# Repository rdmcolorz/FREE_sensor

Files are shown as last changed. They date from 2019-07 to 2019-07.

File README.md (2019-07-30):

# FREE Sensor
_"Wildfires have changed, It's time the technology to fight them does too."_

FREE Sensor is a device firefighters use to detect harmful gasses and to track status of individual firefighters. 

title (https://www.youtube.com/watch?v=2XaswEznusA&feature=youtu.be)
_click for video_

## IBM Cloud services

`IBM Watson IoT Platform` for streaming IoT data and managing IoT devices  
`Cloudant` database for storing history IoT data  
`IBM Watson Studio / Data refinery` for data transformation and parsing  
`IBM Watson Studio / Cognos Dashboard` for data visualization and analytics  

## Getting Started

Follow this [tutorial](https://developer.ibm.com/recipes/tutorials/run-an-esp8266arduino-as-a-iot-foundation-managed-device/) to connect ESP8266 with the IoT platform. For current setup, on the IBM Watson IoT Platform, change `Default Rule` in `Security` to `TLS Optional` to connect with ESP.

To setup history database for IoT data, go to `Extensions` > `Histroical Data Storage` and choose the `Cloudant` service you have created.

Open `IBM Watson Studio` to get access to the database and add connection.

Please message [Taylor](rainbowwww5@gmail.com) to be added to the Watson Studio project.

### Prerequisites

For Taylor's setup you will be using these hardware products:

* [NodeMCU Esp8266](https://www.handsontec.com/pdf_learn/esp8266-V10.pdf) - Main microprocessor
* [Beginner's Guide to ESP8266](https://tttapa.github.io/ESP8266/Chap01%20-%20ESP8266.html)
* [Adafruit SHT31-D Temperature & Humidity Sensor Breakout](https://learn.adafruit.com/adafruit-sht31-d-temperature-and-humidity-sensor-breakout/assembly) - Temperature / Humidity Sensor breakout board
* [MicroSD Shield Adapter](https://www.ebay.com/i/173320605763?itemid=173320605763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) - MicroSD card reader
* [Powered Carbon Monoxide Sensor](https://cdn.sparkfun.com/datasheets/Sensors/Biometric/MQ-7%20Ver1.3%20-%20Manual.pdf) - First prototype sensor
* [Low Power Carbon Monoxide Sensor](https://www.spec-sensors.com/wp-content/uploads/2016/04/3SP_CO_1000-C-Package-110-109.pdf) - Second prototype sensor
* [Adafruit GPS breakout board](https://cdn-learn.adafruit.com/downloads/pdf/adafruit-ultimate-gps.pdf) - GPS module

## Prototyping

Our early prototyping consisted of taking individual sensor components and producing a serial communication readout of the live data. We used the NodeMCU controller to drive the other sensors. 

foo Prototype 1
bar Prototype 2

One major setback we faced was the original CO sensor we used. The sensor die had an operating temperature of over 100°C. This was a massive drain on our battery, and ultimately the bottleneck in miniturizing our device. Thankfully, we found an alternative sensor that has an extremely low-power profile and rated to remain opperational for nearly ten years. This significantly freed up constraints on how small and light our device could become.
There is a limitation using the original MQ-7 sensor as it requires a 90 second warm-up phase and can then collect data and average over one minute for accurate results. This limits data gathering to once every 5 or 10 minutes depending on the final battery used and needed battery life in the field. 
The roadmap for the hardware will include evaluating the 3SP_CO_1000 Spec Sensor, which requires no warmup, but is more expensive. We will also add GPS and humidity sensors. 

Once we tested all the sensors and had their output saving accurately, we combined their output into a test .csv to feed into the IBM cloud. Once on the cloud, we could start analyzing and visualizing the data using IBM computing services. This allowed us to produce remarkable information from our sensor data.

When we started working on IBM Cloud, it was simple to set up an IoT platform and start using simulated devices to get a sense of what data is collected. There was also documentation on setting up an esp8266 device to connect to the platform which was exactly what we needed. Collecting the historic data by setting up a Cloudant for IoT data storage is also quick to implement. After the data is inside the database, we connected Watson studio to the data and used data refinery to parse and transform the data. After data refinery outputs the cleaned data, we can then push it to the Cognos Dashboard, where we can easily drag and drop data into graphs to visualize and analyze our data. We set up the whole pipeline without writing any code, which was a fast and easy experience!

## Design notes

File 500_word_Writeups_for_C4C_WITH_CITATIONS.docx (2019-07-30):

10 WORDS

Sensor data/analytics to reduce wildfire responder exposure to smoke.

499 WORDS

THE OPPORTUNITY

Wildfires have intensified in scale and impact in the last few decades¹. Yet there’s limited data available to understand the long-term effects of smoke exposure among first responders on the front lines². For instance, cardiovascular and neurological diseases are believed to be linked to high levels of carbon monoxide (CO) exposure²,³,⁴.

CO is one harmful component of smoke, is a toxic, odorless, colorless gas which can have immediate effects on physical and mental performance, often unnoticed by the person exposed⁵. Current methods of determining the prognosis and treatment can also be subjective and possibly dangerous⁴.

Our research indicated an opportunity to develop on-the-field technology to measure and record CO levels. The solution could also provide large-scale, quantitative data to study CO correlations with other harmful substances such as PM².⁵ and respirable crystalline silica found in smoke²,⁶,⁷,⁸. There’s no wearable, rugged, low-cost CO device available today.

Health professionals and other scientists can use this data to monitor and determine long-term effects of CO on first responders, and perhaps extrapolate the data to improve the clinical care of active and retired first responders.

OUR SOLUTION

The F.R.E.E. (First Responder Emission Evaluator) Sensor technology has two basic functions: 1) Data gathering and upload capabilities through a compact, rugged CO monitoring device worn by first responders in the field, and 2) Provision of a data dashboard, allowing support teams to make safer deployment decisions based on CO exposure of individual crew members.

The wearable CO sensor was designed with the following parameters: 1) Low cost, 2) IoT solution leveraging the IBM Cloud, 3) Built-in memory card, 4) Low power consumption for long battery life, and 5) Accuracy. IBM technologies employed are the DB2 database, Watson Studio for visualization, and IBM AI to analyze patterns that might help correlate CO levels to PM2.5 and other toxins exposure.

We constructed two prototypes. Both used the MQ-7 CO sensor, SD memory card, Arduino base board, and temperature sensor. Because the MQ-7 CO sensor consumes excessive power during warm-up, we are also evaluating the 3SP_CO_1000 Spec Sensor, a more expensive but low-power component.

The main prototype uploads data to the IBM Cloud via a micro USB cable, and the other uses a Bluno Arduino with built-in Bluetooth, allowing transfer via cellphone for upload to the Cloud when coverage is available.

We envision two uses for the data. The first would populate a data dashboard for support personnel charged with deploying fire crew resources. The data could be incorporated into existing resource management/scheduling software or we could provide a stand-alone dashboard app that fire captains can utilize on their cellphones. The second could be used by medical professionals and researchers to analyze impacts of cumulative exposure, help set occupational exposure limits, and improve the diagnosis and treatment of affected first responders.

F.R.E.E. Sensor is a groundbreaking opportunity to mine large-scale data from first responder CO exposure. Its data dashboard will be invaluable for rapid decision-making in managing fire crew exposure to smoke at the front lines.

REFERENCES

¹Kenward, A., Sanford, T., Bronzan, J. “Western Wildfires – A Fiery Future.” Climate Central. https://assets.climatecentral.org/pdfs/westernwildfires2016v2.pdf (accessed July 23, 2019).

²Domitrovich, J.W. et al. “Wildland Fire Smoke Health Effects on Wildland Firefighters and the Public” Joint Fire Science Program. https://wildfiretoday.com/documents/FirefighterSmokeHealthRisk.pdf (accessed July 23, 2019).

³ Beppu, T. “The Role of MR Imaging in Assessment of Brain Damage from Carbon Monoxide Poisoning: A Review of the Literature.” The American Journal of Neuroradiology, April 2014. http://www.ajnr.org/content/35/4/625 (accessed July 23, 2019).

⁴ Feng-You Lee, Wei-Kung Chen, Cheng-Li Lin, and Chia-Hung Kao. “Carbon Monoxide Poisoning and Subsequent Cardiovascular Disease Risk.” National Library of Medicine, National Institutes of Health. https://www.ncbi.nlm.nih.gov/pmc/articles/PMC4602477/ (accessed July 23, 2019).

⁵ CDC. “Clinical Guidance for Carbon Monoxide (CO) Poisoning After a Disaster.” Center for Disease Control and Prevention. https://www.cdc.gov/disasters/co_guidance.html (accessed July 23, 2019)

⁶ Urbanski, S.P. “Re[2]: Smoke composition ratios for CO and PM2.5 in Wildfires.” Message to Roy Stahl. 4 June 2019. Email.

⁷ Reinhardt, T.E. and Ottmar, R.D. “Baseline Measurements of Smoke Exposure Among Wildland Firefighters” Journal of Occupational and Environmental Hygiene. https://www.fs.fed.us/pnw/fera/publications/fulltext/reinhardtandottmar2004.pdf (accessed July 23, 2019).

⁸ Reinhardt, T.E., Ottmar, R.D and Hanneman, A.J.S. “Smoke Exposure

Among Firefighters at Prescribed Burns in the Pacific Northwest.” USDA Forest Service. https://www.fs.fed.us/pnw/pubs/pnw_rp526.pdf (accessed July 23, 2019).

OTHER interesting stuff:

How NASA measure CO from wildfires

https://climate.nasa.gov/news/2781/carbon-monoxide-from-california-wildfires-drifts-east/

High exposure increases risk of disease among firefighters

https://wildfiretoday.com/2018/02/06/study-shows-firefighters-exposure-smoke-increases-disease-risk/

This mentions the use of CO detectors in the field:

https://www.fs.fed.us/air/health_impacts.htm

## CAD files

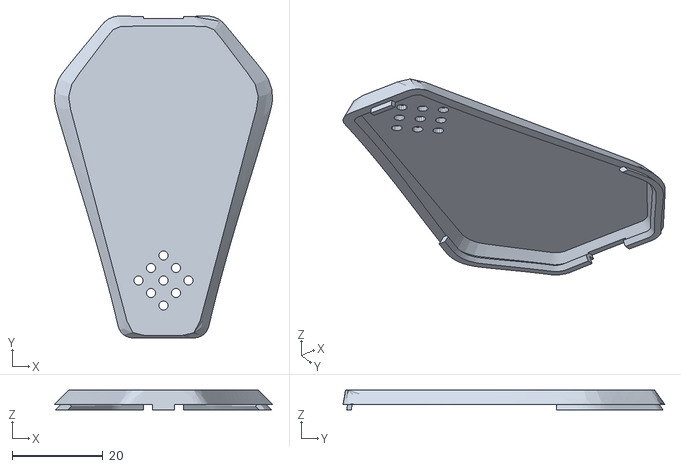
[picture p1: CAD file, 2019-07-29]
3d_model/spottech_top.stl
48.1 x 70.9 x 4.30

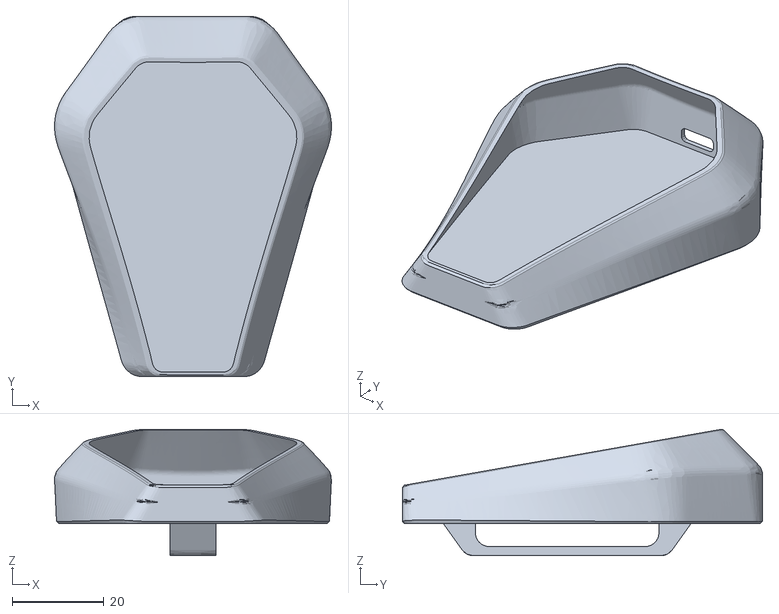
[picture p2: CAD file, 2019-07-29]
3d_model/spottech_bot.stl
60.4 x 78.6 x 27.6

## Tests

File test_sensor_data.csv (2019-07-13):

id | temperature | humidity | co | timestamp
fire1 | 29.1 | 50.2 | 0.29 | 12:23:44
fire1 | 30.1 | 51.2 | 0.30 | 12:23:45
fire1 | 30.2 | 51.1 | 0.29 | 12:23:46
fire1 | 30.5 | 51.4 | 0.29 | 12:23:47
fire1 | 30.4 | 51.3 | 0.27 | 12:23:48

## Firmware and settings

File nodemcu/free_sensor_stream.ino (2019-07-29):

/**
 IBM IoT Foundation managed Device

 Author: Ant Elder
 License: Apache License v2
*/
#include <ESP8266WiFi.h>
#include <PubSubClient.h> // https://github.com/knolleary/pubsubclient/releases/tag/v2.3
#include <ArduinoJson.h> // https://github.com/bblanchon/ArduinoJson/releases/tag/v5.0.7
#include "Adafruit_SHT31.h"

//-------- Customise these values -----------
const char* ssid = "___";
const char* password = "___";

#define ORG "___"
#define DEVICE_TYPE "___"
#define DEVICE_ID "___"
#define TOKEN "___"
//-------- Customise the above values --------

char server[] = ORG ".messaging.internetofthings.ibmcloud.com";
char authMethod[] = "use-token-auth";
char token[] = TOKEN;
char clientId[] = "d:" ORG ":" DEVICE_TYPE ":" DEVICE_ID;
Adafruit_SHT31 sht31 = Adafruit_SHT31();

const char publishTopic[] = "iot-2/evt/status/fmt/json";
const char responseTopic[] = "iotdm-1/response";
const char manageTopic[] = "iotdevice-1/mgmt/manage";
const char updateTopic[] = "iotdm-1/device/update";
const char rebootTopic[] = "iotdm-1/mgmt/initiate/device/reboot";

void callback(char* topic, byte* payload, unsigned int payloadLength);

WiFiClient wifiClient;
PubSubClient client(server, 1883, callback, wifiClient);

int publishInterval = 10000; // 30 seconds
long lastPublishMillis;

void setup() {
 Serial.begin(9600); Serial.println();

 wifiConnect();
 mqttConnect();
 initManagedDevice();
   if (!sht31.begin(0x44)) 
  {
    Serial.println("Couldn't find SHT31");
    while (1) delay(1);
  }
}

void loop() {
 if (millis() - lastPublishMillis > publishInterval) {
   publishData();
   lastPublishMillis = millis();
 }

 if (!client.loop()) {
   mqttConnect();
   initManagedDevice();
 }
}

void wifiConnect() {
 Serial.print("Connecting to "); Serial.print(ssid);
 WiFi.begin(ssid, password);
 while (WiFi.status() != WL_CONNECTED) {
   delay(500);
   Serial.print(".");
 }
 Serial.print("nWiFi connected, IP address: "); Serial.println(WiFi.localIP());
}

void mqttConnect() {
 if (!!!client.connected()) {
   Serial.print("Reconnecting MQTT client to "); Serial.println(server);
   while (!!!client.connect(clientId, authMethod, token)) {
     Serial.print(".");
     delay(500);
   }
   Serial.println();
 }
}

void initManagedDevice() {
 if (client.subscribe("iotdm-1/response")) {
   Serial.println("subscribe to responses OK");
 } else {
   Serial.println("subscribe to responses FAILED");
 }

 if (client.subscribe(rebootTopic)) {
   Serial.println("subscribe to reboot OK");
 } else {
   Serial.println("subscribe to reboot FAILED");
 }

 if (client.subscribe("iotdm-1/device/update")) {
   Serial.println("subscribe to update OK");
 } else {
   Serial.println("subscribe to update FAILED");
 }

 StaticJsonBuffer<300> jsonBuffer;
 JsonObject& root = jsonBuffer.createObject();
 JsonObject& d = root.createNestedObject("d");
 JsonObject& metadata = d.createNestedObject("metadata");
 metadata["publishInterval"] = publishInterval;
 JsonObject& supports = d.createNestedObject("supports");
 supports["deviceActions"] = true;

 char buff[300];
 root.printTo(buff, sizeof(buff));
 Serial.println("publishing device metadata:"); Serial.println(buff);
 if (client.publish(manageTopic, buff)) {
   Serial.println("device Publish ok");
 } else {
   Serial.print("device Publish failed:");
 }
}

void publishData() {
  float t = sht31.readTemperature();
  float h = sht31.readHumidity();
  Serial.println(t);
 String payload = "{\"d\":{\"counter\":";
 payload += millis() / 1000;
 payload += ",\"temp\":";
 payload += t;
 payload += ",\"hum\":";
 payload += h;
 payload += "}}";

 Serial.print("Sending payload: "); Serial.println(payload);

 if (client.publish(publishTopic, (char*) payload.c_str())) {
   Serial.println("Publish OK");
 } else {
   Serial.println("Publish FAILED");
 }
}

void callback(char* topic, byte* payload, unsigned int payloadLength) {
 Serial.print("callback invoked for topic: "); Serial.println(topic);

 if (strcmp (responseTopic, topic) == 0) {
   return; // just print of response for now
 }

 if (strcmp (rebootTopic, topic) == 0) {
   Serial.println("Rebooting...");
   ESP.restart();
 }

 if (strcmp (updateTopic, topic) == 0) {
   handleUpdate(payload);
 }
}

void handleUpdate(byte* payload) {
 StaticJsonBuffer<300> jsonBuffer;
 JsonObject& root = jsonBuffer.parseObject((char*)payload);
 if (!root.success()) {
   Serial.println("handleUpdate: payload parse FAILED");
   return;
 }
 Serial.println("handleUpdate payload:"); root.prettyPrintTo(Serial); Serial.println();

 JsonObject& d = root["d"];
 JsonArray& fields = d["fields"];
 for (JsonArray::iterator it = fields.begin(); it != fields.end(); ++it) {
   JsonObject& field = *it;
   const char* fieldName = field["field"];
   if (strcmp (fieldName, "metadata") == 0) {
     JsonObject& fieldValue = field["value"];
     if (fieldValue.containsKey("publishInterval")) {
       publishInterval = fieldValue["publishInterval"];
       Serial.print("publishInterval:"); Serial.println(publishInterval);
     }
   }
 }
}

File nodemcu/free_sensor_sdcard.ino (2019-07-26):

#include <Arduino.h>
#include <Wire.h>
#include "Adafruit_SHT31.h"
#include <SPI.h>
#include <SD.h>
 
Adafruit_SHT31 sht31 = Adafruit_SHT31();
byte inByte;
//bool sdInitSuccess = false; //card init status
File myFile;

String readText;
char readCharArray[128];
unsigned long fileSize;
unsigned long filePos = 0;
String FILE_NAME = "data20.txt";
byte DEBUG = 1;
String STATE;

void setup() 
{
  STATE = "WRITE";
  Serial.begin(9600);
  while (!Serial) {
    ; //wait for the serial port to connect.
  }
  
  // start up the adafruit_sht31 temp / humidity sensor according to the setup link at 0x44
  if (!sht31.begin(0x44)) 
  {
    if (DEBUG) Serial.println("Couldn't find SHT31");
    while (1) delay(1);
  }
  delay(5000);
  Serial.println("Setup SD");
  // start up the SD card reader at pin D8
  if (!SD.begin(D8)) {
    if (DEBUG) Serial.println("Initializing SD card");
    while (1) delay(1);
  }
  else {
    if (DEBUG) Serial.println("Initialize Sucess");
  }
}

//String readUntil(File &myFile, char n) { //read until n
//  int i = 0;
//  myFile.seek(filePos); //read from current filepos
//  
//  do {
//    if (myFile.peek() != -1) { //check if file is empty
//      readCharArray[i++] = myFile.read(); //read otherwise
//      filePos++; //advance the filepos
//    }
//  } while ((myFile.peek() != -1) && (readCharArray[i - 1] != n)); //if not eof | \n
//  if (myFile.peek() == -1) { //if eof reached
//    filePos = 0; //if eof, reset to start pos
//  }
//  readCharArray[i - 1] = '\0'; //remove the extra \n
//  return readCharArray;
//}

String ENDF2(String &p_line, int &p_start, char p_delimiter) {
//EXTRACT NEXT DELIMITED FIELD VERSION 2
//Extract fields from a line one at a time based on a delimiter.
//Because the line remains intact we dont fragment heap memory
//p_start would normally start as 0
//p_start increments as we move along the line
//We return p_start = -1 with the last field

  //If we have already parsed the whole line then return null
  if (p_start == -1) {
    return "";
  }

  int l_start = p_start;
  int l_index = p_line.indexOf(p_delimiter,l_start);
  if (l_index == -1) { //last field of the data line
    p_start = l_index;
    return p_line.substring(l_start);
  }
  else { //take the next field off the data line
    p_start = l_index + 1;
    return p_line.substring(l_start,l_index); //Include, Exclude
  }
}

void writeString(String stringData) { // Used to serially push out a String with Serial.write()

  for (int i = 0; i < stringData.length(); i++) {
    Serial.write(stringData[i]);   // Push each char 1 by 1 on each loop pass
  }
  Serial.write('\n');
}

String read_all(File &myFile) {
  String l_line;
    l_line.reserve(128); //Avoids heap memory fragmentation
                         //Reserve space for your longest expected data line
    while (myFile.available()) {
      l_line = myFile.readStringUntil('\n');
      l_line.trim();
      if (l_line != "") {
        int l_start_posn = 0;
        while (l_start_posn != -1) {
          String outline;
          outline = ENDF2(l_line,l_start_posn,'\n');
          writeString(outline);
        }
      } //skip blank (NULL) lines
    }//Read the file line by line
}


void write_data() {
// writes sensor data to sdcard, currently only temperature and humidity from sht31
// board
// Closing the file actually copies the partial buffer to the file, and closes the file.
// It is that copying of the buffer to the file that takes most of the time.

  float t = sht31.readTemperature();
  float h = sht31.readHumidity();
  
  if (DEBUG) {
    Serial.print(t);
    Serial.print(",");
    Serial.println(h);
  }
  
  myFile = SD.open(FILE_NAME, FILE_WRITE);
  if (myFile) {
    if (!isnan(t) && !isnan(h)) {
      myFile.print(t);
      myFile.print(",");
      myFile.println(h);
      myFile.close(); //this writes to the card
    }
    else { 
      if (DEBUG) Serial.println("Failed to read sht31 (temperature/humidity)");
    }
  }
  else { 
    if (DEBUG) Serial.println("Error opeing file.\n");
  }
}

void read_data() {
// writes data read from the file on the microSD card through Serial.write()
// after reading the file, the esp will go into standby mode and will not
// write any data into file.

  myFile = SD.open(FILE_NAME);
  
  if (myFile) {
    read_all(myFile);
  }
  STATE = "STANDBY";
  myFile.close();
}

void loop() 
{
  if (Serial.available() > 0) {
    inByte = Serial.read();
  }
  if (inByte == '1') { // when we want to read the recorded file to the cloud
    STATE = "READ";
  }
  else if (inByte == '2') {
    STATE = "WRITE";
  }
  
  if (STATE == "READ") {
    read_data();
    Serial.println("END");
  }
  if (STATE == "STANDBY") {
    if (DEBUG) {
      Serial.println("***********");
      Serial.println("Standing by");
    }
  }
  if (STATE == "WRITE") {
    write_data();
    delay(2000);
  }
}

//    else if (inByte == 'r' || inByte == 'R') {
//      if (sdInitSuccess) { //proceed only if card is initialized
//        myFile = SD.open("TEST.txt");
//        if (myFile) {
//          Serial.println("File opened successfully.");
//          Serial.println("Reading from TEST.text");
//          readText = (String) readUntil(myFile, 10); //read until newline
//          Serial.print(readText);
//          Serial.print(", ");
//          Serial.println(filePos); //print current file position
//          Serial.println();
//          myFile.close();
//        }
//        else {
//          Serial.println("Error opening file.\n");
//        }

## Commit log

2019-07-05 working code for sht31 sensor data to sdcard
2019-07-13 read file from sdcard to serial port
    [test_sensor_data.csv]
2019-07-15 got esp setup ready, serial reader not working though
    [read_serial.py, upload_cloud.py]
2019-07-21 got reading from sd card and made sql insert table command
2019-07-29 Updoot with prototype started
    Prototype description
2019-07-30 Prototype updoot
    Added our sensor tech swap info
